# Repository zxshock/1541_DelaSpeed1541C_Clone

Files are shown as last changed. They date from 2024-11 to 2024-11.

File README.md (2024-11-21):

Done in 2017, based on a historic PCB I managed to obtain. Needs additional SpeedDOS style parallel cable between C64 and 1541.
Sadly we never found the corresponding C64 Kernal - if my memory serves me right, this also works with "SpeedDOS Pro" ROMs.

Documentation is a mess - as usual. Uploaded completely "as is", since I lost all interest in the Commodore community.
Uploaded for your personal enjoyment. If I see this advertised as "r@r3 l@@k - high quality Repro of a long lost expansion!!!!!!11one" for 50€+ on eBay I sincerely hope you're getting the customers you deserve :)

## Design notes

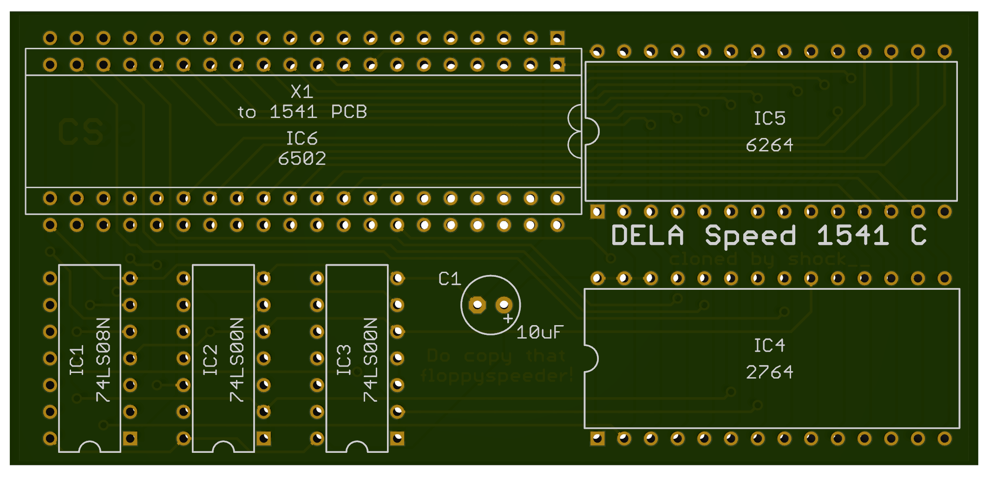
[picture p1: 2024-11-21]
preview.png

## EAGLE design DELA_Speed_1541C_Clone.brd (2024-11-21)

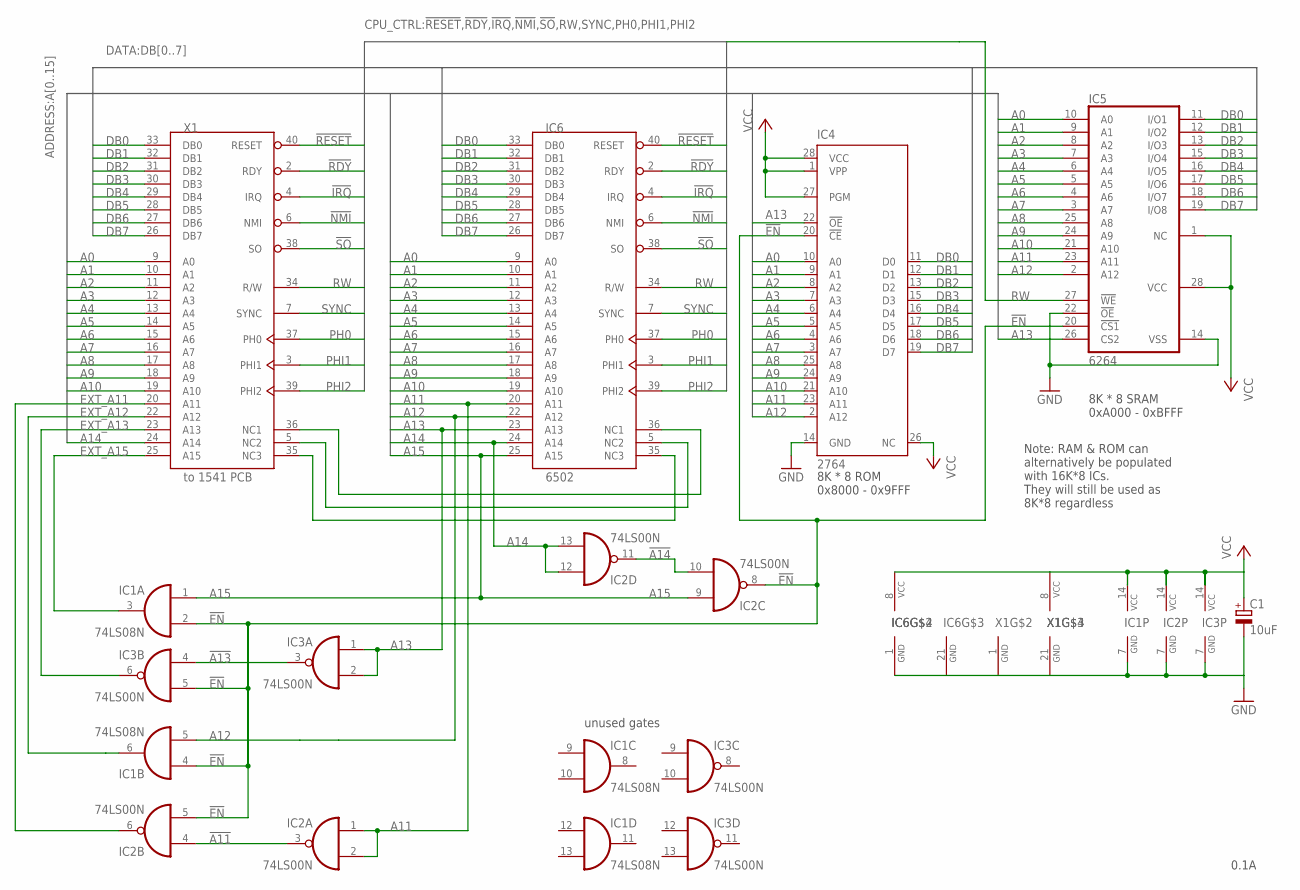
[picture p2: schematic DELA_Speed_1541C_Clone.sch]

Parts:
C1: 10uF; E2,5-6
IC1: 74LS08N; DIL14
IC2, IC3: 74LS00N; DIL14
IC4: 2764; DIL28-6
IC5: 6264; DIL28-6
IC6: 6502; DIP40
X1: to 1541 PCB; DIP40

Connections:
!A11: IC2.3 (O), IC2.4 (I0)
!A13: IC3.3 (O), IC3.4 (I0)
!A14: IC2.10 (I1), IC2.11 (O)
!EN: IC1.2 (I1), IC1.4 (I0), IC2.5 (I1), IC2.8 (O), IC3.5 (I1), IC4.20 (!CE), IC5.20 (!CS1)
!IRQ: IC6.4 (IRQ), X1.4 (IRQ)
!NMI: IC6.6 (NMI), X1.6 (NMI)
!RDY: IC6.2 (RDY), X1.2 (RDY)
!RESET: IC6.40 (RESET), X1.40 (RESET)
!SO: IC6.38 (SO), X1.38 (SO)
A0: IC4.10 (A0), IC5.10 (A0), IC6.9 (A0), X1.9 (A0)
A1: IC4.9 (A1), IC5.9 (A1), IC6.10 (A1), X1.10 (A1)
A2: IC4.8 (A2), IC5.8 (A2), IC6.11 (A2), X1.11 (A2)
A3: IC4.7 (A3), IC5.7 (A3), IC6.12 (A3), X1.12 (A3)
A4: IC4.6 (A4), IC5.6 (A4), IC6.13 (A4), X1.13 (A4)
A5: IC4.5 (A5), IC5.5 (A5), IC6.14 (A5), X1.14 (A5)
A6: IC4.4 (A6), IC5.4 (A6), IC6.15 (A6), X1.15 (A6)
A7: IC4.3 (A7), IC5.3 (A7), IC6.16 (A7), X1.16 (A7)
A8: IC4.25 (A8), IC5.25 (A8), IC6.17 (A8), X1.17 (A8)
A9: IC4.24 (A9), IC5.24 (A9), IC6.18 (A9), X1.18 (A9)
A10: IC4.21 (A10), IC5.21 (A10), IC6.19 (A10), X1.19 (A10)
A11: IC2.1 (I0), IC2.2 (I1), IC4.23 (A11), IC5.23 (A11), IC6.20 (A11)
A12: IC1.5 (I1), IC4.2 (A12), IC5.2 (A12), IC6.22 (A12)
A13: IC3.1 (I0), IC3.2 (I1), IC4.22 (!OE), IC5.26 (CS2), IC6.23 (A13)
A14: IC2.12 (I0), IC2.13 (I1), IC6.24 (A14), X1.24 (A14)
A15: IC1.1 (I0), IC2.9 (I0), IC6.25 (A15)
DB0: IC4.11 (D0), IC5.11 (I/O1), IC6.33 (DB0), X1.33 (DB0)
DB1: IC4.12 (D1), IC5.12 (I/O2), IC6.32 (DB1), X1.32 (DB1)
DB2: IC4.13 (D2), IC5.13 (I/O3), IC6.31 (DB2), X1.31 (DB2)
DB3: IC4.15 (D3), IC5.15 (I/O4), IC6.30 (DB3), X1.30 (DB3)
DB4: IC4.16 (D4), IC5.16 (I/O5), IC6.29 (DB4), X1.29 (DB4)
DB5: IC4.17 (D5), IC5.17 (I/O6), IC6.28 (DB5), X1.28 (DB5)
DB6: IC4.18 (D6), IC5.18 (I/O7), IC6.27 (DB6), X1.27 (DB6)
DB7: IC4.19 (D7), IC5.19 (I/O8), IC6.26 (DB7), X1.26 (DB7)
EXT_A11: IC2.6 (O), X1.20 (A11)
EXT_A12: IC1.6 (O), X1.22 (A12)
EXT_A13: IC3.6 (O), X1.23 (A13)
EXT_A15: IC1.3 (O), X1.25 (A15)
GND: C1.-, IC1.7 (GND), IC2.7 (GND), IC3.7 (GND), IC4.14 (GND), IC5.14 (VSS), IC5.22 (!OE), IC6.1 (GND), IC6.21 (GND), X1.1 (GND), X1.21 (GND)
NC1: IC6.36 (NC1), X1.36 (NC1)
NC2: IC6.5 (NC2), X1.5 (NC2)
NC3: IC6.35 (NC3), X1.35 (NC3)
PH0: IC6.37 (PH0), X1.37 (PH0)
PHI1: IC6.3 (PHI1), X1.3 (PHI1)
PHI2: IC6.39 (PHI2), X1.39 (PHI2)
RW: IC5.27 (!WE), IC6.34 (R/W), X1.34 (R/W)
SYNC: IC6.7 (SYNC), X1.7 (SYNC)
VCC: C1.+, IC1.14 (VCC), IC2.14 (VCC), IC3.14 (VCC), IC4.1 (VPP), IC4.26 (NC), IC4.27 (PGM), IC4.28 (VCC), IC5.1 (NC), IC5.28 (VCC), IC6.8 (VCC), X1.8 (VCC)

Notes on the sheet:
unused gates
0.1A
8K * 8 SRAM 0xA000 - 0xBFFF
8K * 8 ROM 0x8000 - 0x9FFF
Note: RAM & ROM can alternatively be populated with 16K*8 ICs. They will still be used as 8K*8 regardless

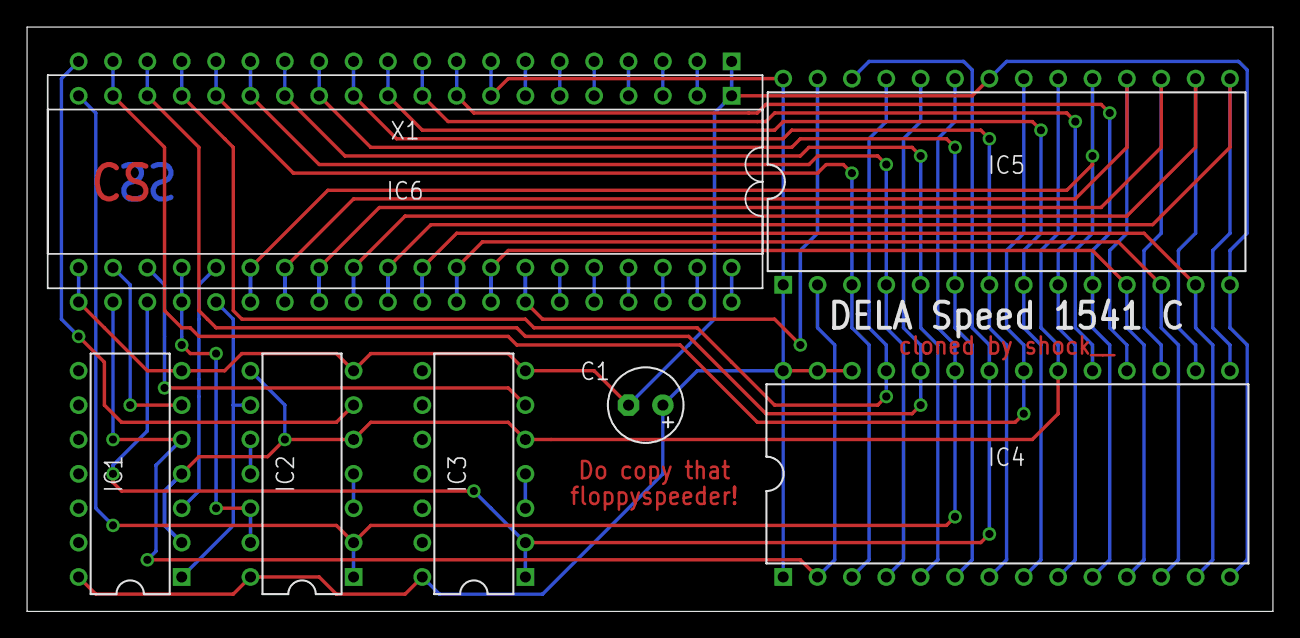
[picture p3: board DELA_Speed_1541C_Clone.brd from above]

Board: 2 copper layers, 92.1 x 43.2 mm, 8 parts (0 on the bottom side), 47 nets.
